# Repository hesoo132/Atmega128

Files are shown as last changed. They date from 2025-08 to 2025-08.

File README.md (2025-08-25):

# ATmega128A Security System Board

> Keypad + LCD + Bluetooth(HC‑06) + Shock Sensor(SW‑420) + Servo Lock + Buzzer
> Education & Smart Access Control Prototyping Platform

---

## 🔎 Overview
The **ATmega128A Security System Board** is a compact AVR platform for **learning, prototyping, and access‑control demos**.
It integrates **12 V → 5 V/3.3 V** power, **USB‑UART**, **ISP programming**, **keypad+LCD UI**, **HC‑06 Bluetooth**, **SW‑420 vibration detection**, **servo lock**, and **buzzer alerts**.

---

## 📸 PCB Overview
| Top View | Bottom View |
|---|---|
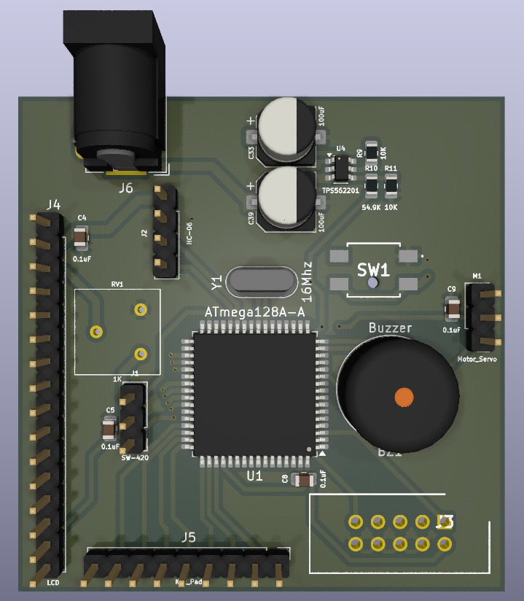
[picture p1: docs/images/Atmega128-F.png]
Top
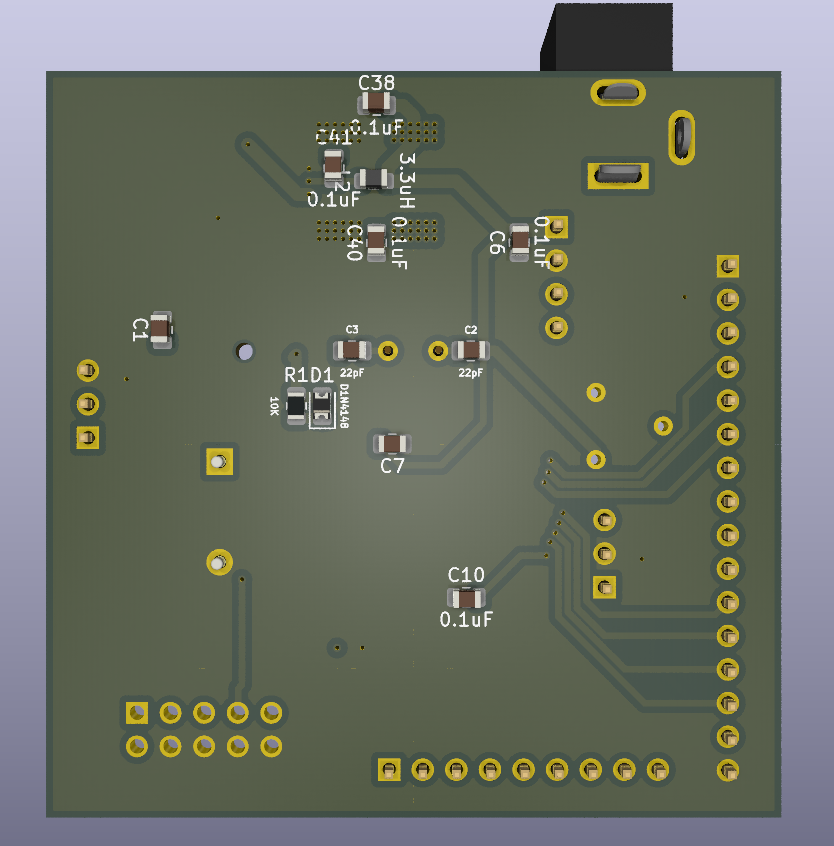
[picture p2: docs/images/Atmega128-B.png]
Bottom
|  |  |

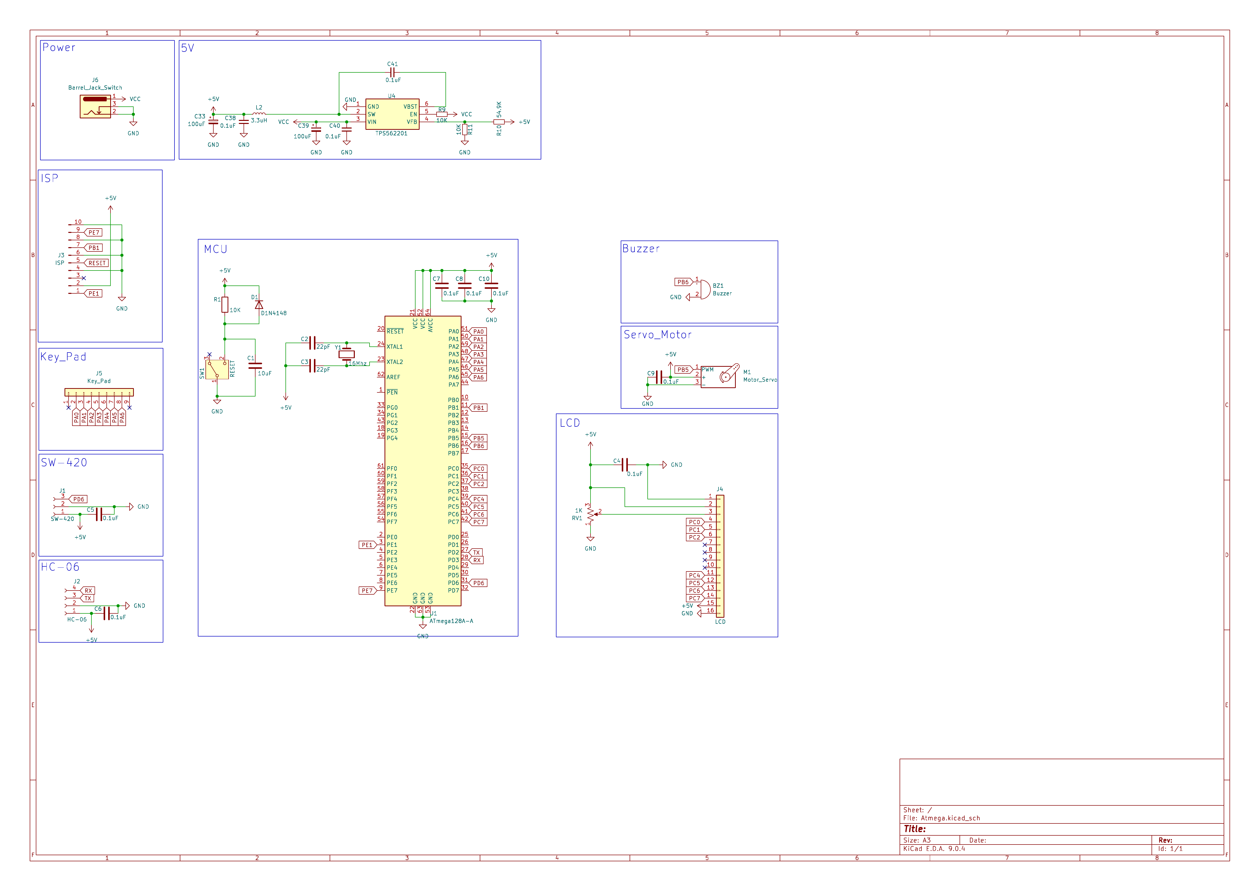
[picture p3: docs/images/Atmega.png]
Schematic
> Schematics (PNG): 

---

## 📑 Design Resources
- **MCU**: ATmega128A‑AU (8‑bit AVR)
- **EDA**: KiCad 9.0.x
- **Board**: 2‑layer

---

## ⚙️ Key Hardware Notes
- **Power**: 12 V barrel jack → **TPS562201‑5.0 / TPS562201‑3.3** rails
- **Clock**: 16 MHz crystal
- **Programming**: **ISP header** (AVRDUDE/USBasp/Atmel‑ICE)
- **USB‑UART**: FT232RL (debug console / host comms)
- **UI/Peripherals**:
  - **Keypad (J5)**: enter/change password
  - **LCD (J4)**: show result/tries/lockout timer
  - **Servo**: unlock on success; stay locked on failure
  - **Buzzer**: success/fail tone + vibration alarm
  - **SW‑420 (J1)**: shock/vibration tamper detection
  - **HC‑06 (J2)**: Bluetooth data exchange

---

## 🔐 Security‑Oriented Features
| Module | Role |
|---|---|
| **Keypad (J5)** | Password entry / change |
| **LCD (J4)** | Status, error, lockout seconds |
| **Servo** | Door actuation (open on correct PIN) |
| **Buzzer** | Wrong PIN & vibration alarm |
| **SW‑420** | Tamper/shock detection |
| **HC‑06** | Remote monitor & control (UART over BT) |

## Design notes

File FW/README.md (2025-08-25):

# 🔐 ATmega128A Firmware – Smart Locker System

## 🔎 Overview
This firmware is designed for the **ATmega128A Security System Board**.
It integrates keypad password entry, LCD feedback, Bluetooth control, servo motor door actuation, vibration detection, and buzzer alarms.
The system supports **PIN verification, password change, vibration-based tamper alerts, lockout after repeated failures, and remote Bluetooth door control**.

---

## 📊 System Block Diagram
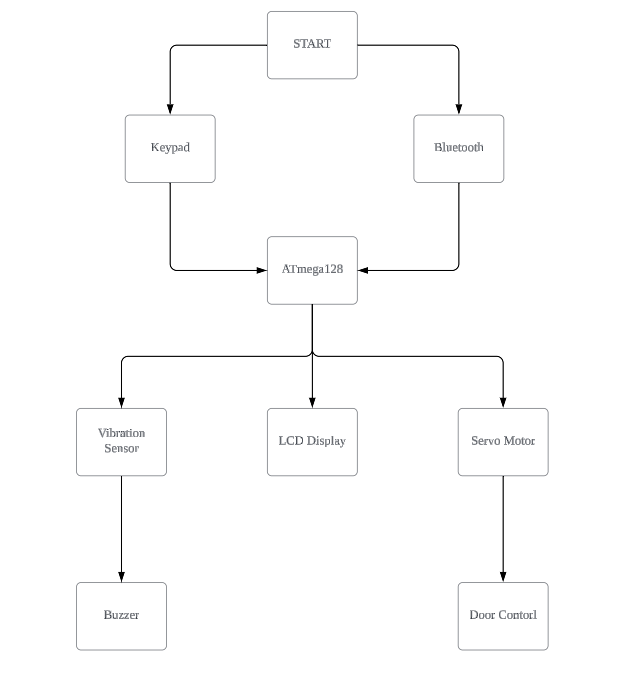
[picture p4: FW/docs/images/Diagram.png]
System Diagram


---

## ⚙️ Features

- **Password Authentication**
  - 4-digit PIN entry via **Keypad (J5)**
  - Password change supported (`*` → old password → new password)
  - LCD shows password entry & system status

- **Door Control**
  - **Servo motor** opens on correct password or Bluetooth `1` command
  - Auto-closes after 10 seconds or `#` press
  - Bluetooth `0` command forces door close

- **Tamper Detection**
  - **SW-420 vibration sensor** monitors physical shock
  - >5 consecutive hits triggers buzzer alarm + LCD warning
  - Resets to password input screen afterward

- **Buzzer Alerts**
  - Success melody (correct PIN / open door)
  - Warning tone (wrong PIN / vibration detected)

- **Security Lockout**
  - After **5 failed attempts**, system locks for **30 seconds**
  - LCD shows countdown timer

- **Bluetooth Remote Control**
  - `1` = Open door
  - `0` = Close door

---

## 🧩 Key Functions in Code

- `InitDevices()` → Peripheral initialization (PWM, UART, GPIO)
- `SetServoAngle(angle)` → Servo motor positioning (−90° closed, +90° open)
- `PlayTone(f, d)` → Generate tone on buzzer (frequency, duration)
- `PlaySuccessTune()` → Melody on successful unlock
- `CheckVibrationSensor()` → Detect repeated vibration & raise alarm
- `KeyScan()` → 4x3 keypad scanning with debounce + beep feedback
- `BluetoothReceive()` → UART0 data polling (HC-06)
- `DisplayMessage(line1, line2)` → LCD line output utility

---

## 📜 Example Workflow
1. **Startup**
   - LCD: `Welcome! Daejin Locker`
   - Prompt: `Insert Password`

2. **Password Handling**
   - User enters 4-digit PIN + `#`
   - If correct → door opens, melody plays
   - If wrong → error tone, retry prompt

3. **Failure Handling**
   - After 5 wrong attempts → 30s lockout
   - LCD shows countdown: `Wait: XX sec`

4. **Tamper Handling**
   - Vibration detected ≥5 times → alarm tone
   - LCD: `Don't hit it!!` → resets to password prompt

5. **Bluetooth**
   - Receive `1` → Door opens
   - Receive `0` → Door closes

---

## 📱 Mobile App (MIT App Inventor)

A companion **Android App** was created using **MIT App Inventor**  
to control the ATmega128A Smart Locker via Bluetooth.

| Main Screen | Sign Up Screen | Control Screen |
|---|---|---|
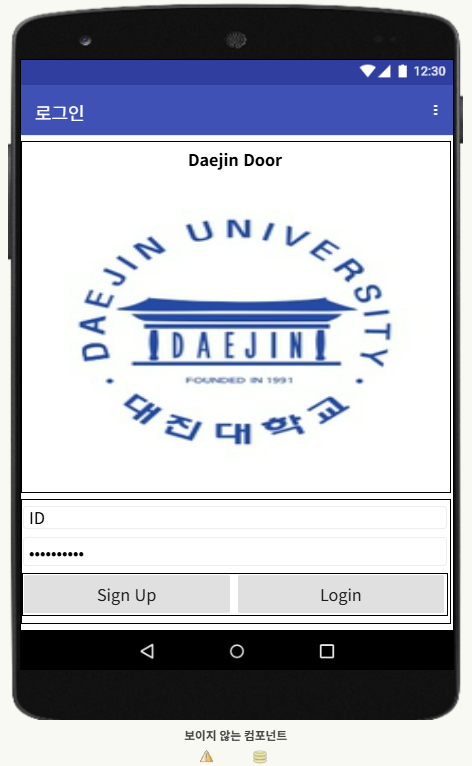
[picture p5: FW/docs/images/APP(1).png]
Main
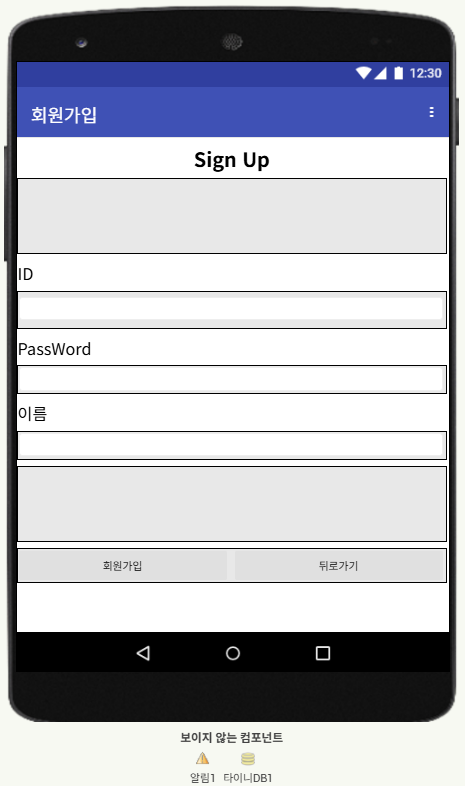
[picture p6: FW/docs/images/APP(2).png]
Sign Up
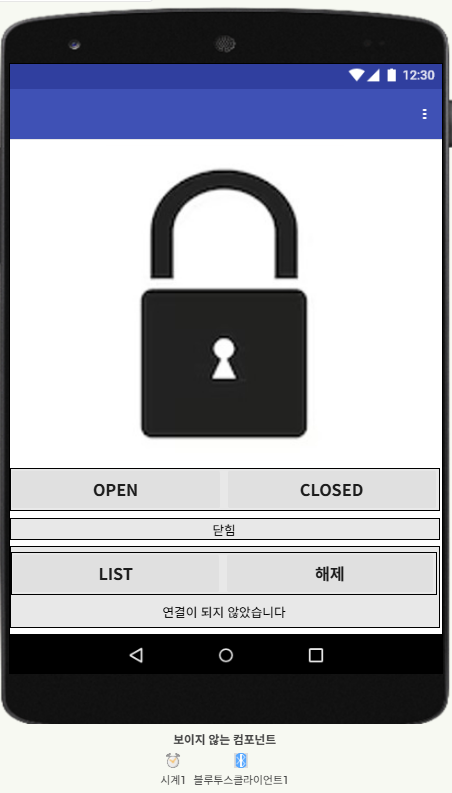
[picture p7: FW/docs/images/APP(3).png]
Control
|  |  |  |

- **Main Screen**
  - Bluetooth pairing, Open/Close control
  - Door status feedback  

- **Login Screen**
  - User authentication (ID + Password)

- **Sign Up Screen**
  - Register new users (ID, Password, Name)

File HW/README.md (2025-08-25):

# ATmega128A Development Board

## 🔎 Overview
The **ATmega128A Development Board** is a versatile embedded platform for **AVR microcontroller learning, prototyping, and embedded system design**.  
It integrates stable power delivery, multiple communication interfaces, keypad & LCD modules, and expansion connectors for external devices.

---

## 📸 PCB Overview
| Top View | Bottom View |
|---|---|
| Top | Bottom |

---

## 📑 Design Resources
- **Schematics**: [Atmega.pdf](Atmega.pdf) (KiCad 9.0.4)

---

## 🔧 Key Hardware Notes
- **EDA Tool**: KiCad 9.0.4  
- **PCB Stackup**: 2-layer standard  
- **MCU**: ATmega128A-AU (8-bit AVR, Ports A–G exposed)  
- **Power**: 12 V input → 5 V & 3.3 V rails (TPS562201 regulators)  
- **Interfaces**: USB-to-Serial (FT232RL), ISP programmer header  
- **User IO**: Keypad, LCD, Servo motor, Buzzer, LEDs  
- **Sensors**: SW-420 vibration/shock sensor  
- **Communication**: HC-06 Bluetooth module

---

## 🧩 Schematic Highlights
MCU
### 1) MCU — ATmega128A-AU  
- **Role**: Central controller for all peripherals  
- **Features**: GPIO Ports A–G, external 16 MHz crystal, reset circuit  
- **Purpose**: Main processing unit for password and control logic

---

### 2) Power
- **Input**: Barrel Jack (12 V)  
- **Regulators**: TPS562201-5.0 & TPS562201-3.3  
- **Purpose**: Stable dual-voltage supply for mixed 5 V / 3.3 V peripherals

---

### 3) Communication 
- **USB-to-Serial**: FT232RL for PC connection & firmware upload  
- **ISP**: 6-pin header for direct programming  
- **Bluetooth (J2)**: HC-06 for wireless communication

---

### 4) User I/O
- **Keypad (J5)**: Password input & modification  
- **LCD (J4)**: Password confirmation, error display, lockout countdown  
- **LEDs (D1–D4)**: Status indicators  
- **Buzzer**: Alarm on wrong password or vibration detection  
- **Servo Motor**: Unlocks on correct password; locked otherwise  
- **SW-420 Sensor (J1)**: Detects vibration/shock for tamper alert

---

## ✅ Progress
- [x] Schematics completed  
- [x] PCB fabricated  
- [x] Power supply tested (5 V / 3.3 V OK)  
- [x] USB-Serial & ISP programming validated  
- [x] Keypad & LCD integrated  
- [x] Bluetooth bring-up (HC-06)  
- [x] Security application firmware in progress

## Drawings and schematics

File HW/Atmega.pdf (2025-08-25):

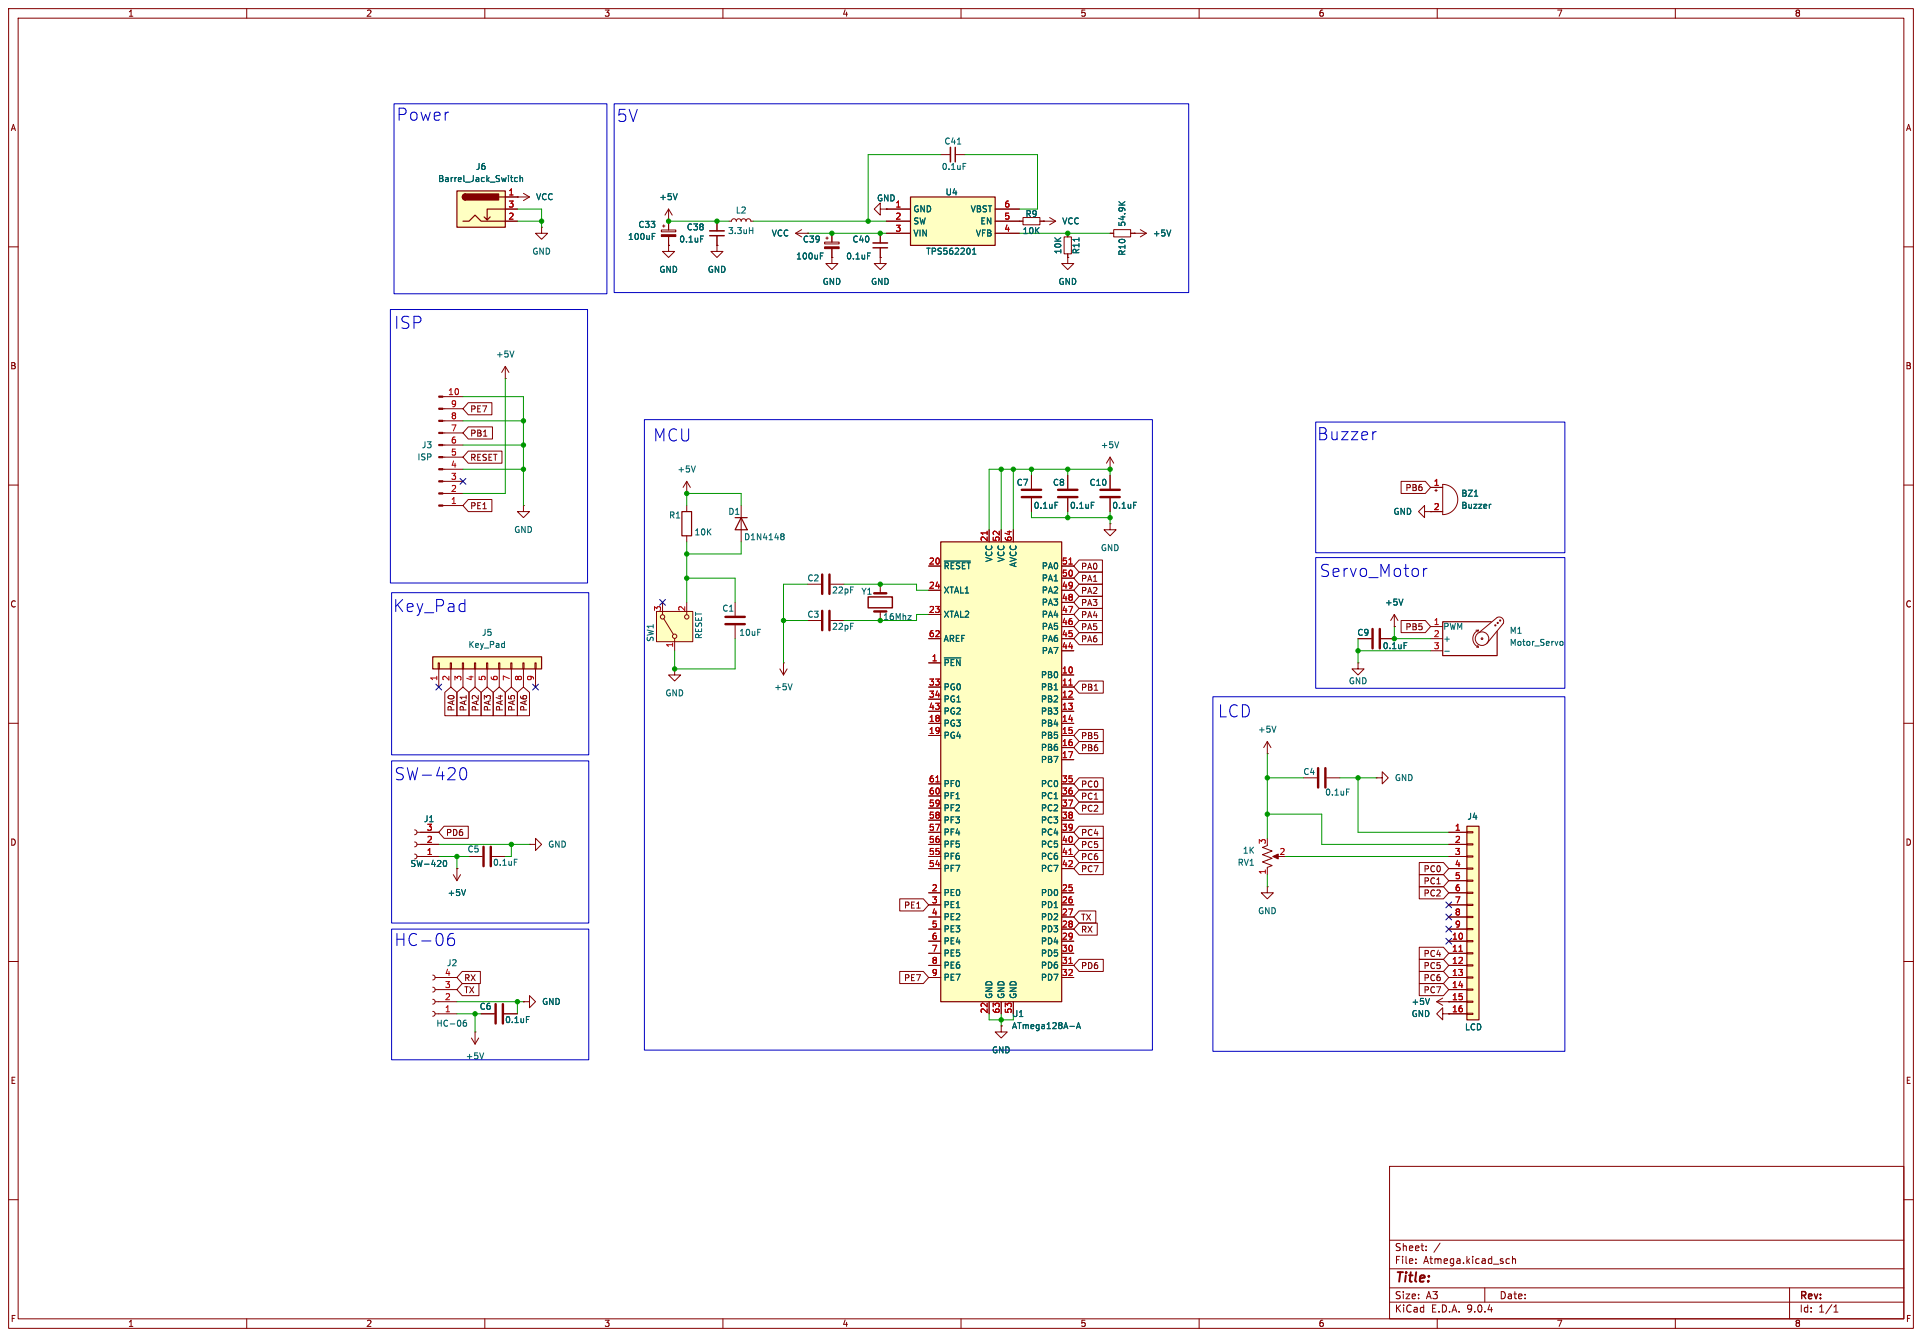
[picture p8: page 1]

Id: 1/1 Title: File: Atmega.kicad_sch Sheet: /

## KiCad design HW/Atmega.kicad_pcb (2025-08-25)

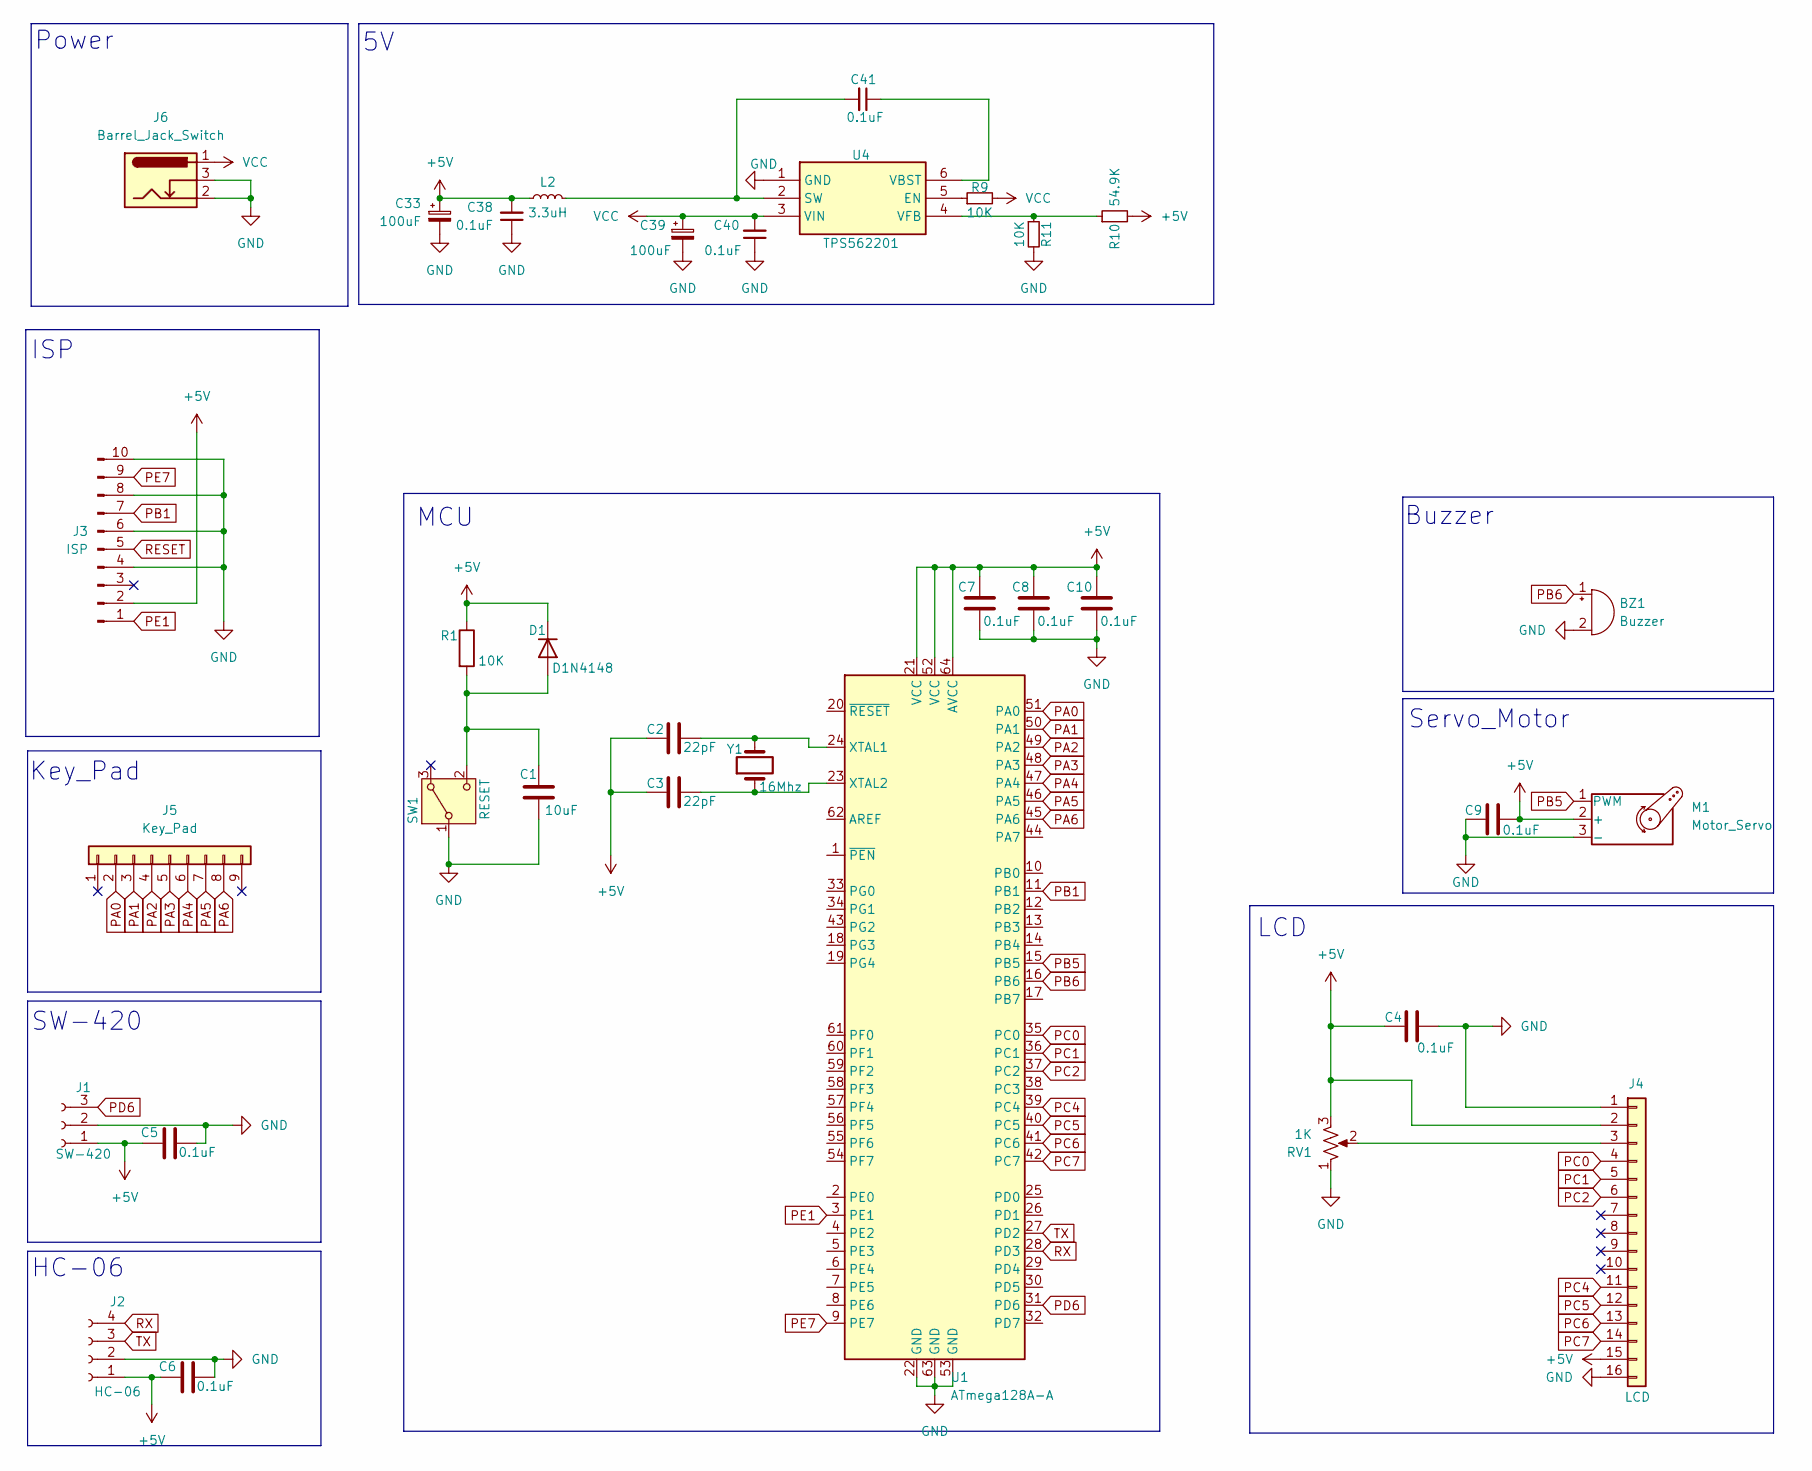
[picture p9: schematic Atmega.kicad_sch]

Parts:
BZ1: Buzzer; Buzzer_12x9.5RM7.6
C1: 10uF; C_0805_2012Metric
C2, C3: 22pF; C_0805_2012Metric
C4, C5, C6, C7, C8, C9, C10, C38, C40, C41: 0.1uF; C_0805_2012Metric
C33, C39: 100uF; CP_Elec_6.3x5.9
D1: D1N4148; D_0805_2012Metric
J1: SW-420; PinHeader_1x03_P2.54mm_Vertical
J2: HC-06; PinHeader_1x04_P2.54mm_Vertical
J3: ISP; SHDR10W64P254_2X5_2036X885X925P
J4: LCD; PinHeader_1x16_P2.54mm_Vertical
J5: Key_Pad; PinHeader_1x09_P2.54mm_Vertical
J6: Barrel_Jack_Switch; BarrelJack_GCT_DCJ200-10-A_Horizontal
L2: 3.3uH; L_0805_2012Metric
M1: Motor_Servo; PinHeader_1x03_P2.54mm_Vertical
R1, R9, R11: 10K; R_0805_2012Metric
R10: 54.9K; R_0805_2012Metric
RV1: 1K; Potentiometer_Bourns_3386F_Vertical
SW1: RESET; TLSMDT3C020GLFS
U1: ATmega128A-A; TQFP-64_14x14mm_P0.8mm
U4: TPS562201; SOT-23-6; Mouser Part Number 595-TPS562201DDCR
Y1: 16Mhz; Crystal_HC52-6mm_Vertical

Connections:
+5V: C2.1, C3.1, C4.1, C5.1, C6.1, C7.2, C8.2, C9.1, C10.2, C33.1, C38.2, D1.1 (K), J1.1, J2.1, J3.2, J4.2, J4.15, L2.2, M1.2 (+), R1.1, R10.2, RV1.3, U1.21 (VCC), U1.52 (VCC), U1.64 (AVCC)
GND: BZ1.2 (-), C1.2, C4.2, C5.2, C6.2, C7.1, C8.1, C9.2, C10.1, C33.2, C38.1, C39.2, C40.1, J1.2, J2.2, J3.4, J3.6, J3.8, J3.10, J4.1, J4.16, J6.2, J6.3, M1.3 (-), R11.2, RV1.1, SW1.1 (B), U1.22 (GND), U1.53 (GND), U1.63 (GND), U4.1 (GND)
unnamed: C1.1, D1.2 (A), R1.2, SW1.2 (C)
unnamed: J4.3, RV1.2
unnamed: C2.2, U1.24 (XTAL1), Y1.2
unnamed: C3.2, U1.23 (XTAL2), Y1.1
unnamed: R9.1, U4.5 (EN)
unnamed: C41.2, L2.1, U4.2 (SW)
unnamed: C41.1, U4.6 (VBST)
unnamed: R10.1, R11.1, U4.4 (VFB)
PA0: J5.2, U1.51 (PA0)
PA1: J5.3, U1.50 (PA1)
PA2: J5.4, U1.49 (PA2)
PA3: J5.5, U1.48 (PA3)
PA4: J5.6, U1.47 (PA4)
PA5: J5.7, U1.46 (PA5)
PA6: J5.8, U1.45 (PA6)
PB1: J3.7, U1.11 (PB1)
PB5: M1.1 (PWM), U1.15 (PB5)
PB6: BZ1.1 (+), U1.16 (PB6)
PC0: J4.4, U1.35 (PC0)
PC1: J4.5, U1.36 (PC1)
PC2: J4.6, U1.37 (PC2)
PC4: J4.11, U1.39 (PC4)
PC5: J4.12, U1.40 (PC5)
PC6: J4.13, U1.41 (PC6)
PC7: J4.14, U1.42 (PC7)
PD6: J1.3, U1.31 (PD6)
PE1: J3.1, U1.3 (PE1)
PE7: J3.9, U1.9 (PE7)
RESET: J3.5
RX: J2.4, U1.28 (PD3)
TX: J2.3, U1.27 (PD2)
VCC: C39.1, C40.2, J6.1, R9.2, U4.3 (VIN)

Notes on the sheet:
Buzzer
ISP
HC-06
Servo_Motor
LCD
Power
MCU
SW-420
Key_Pad

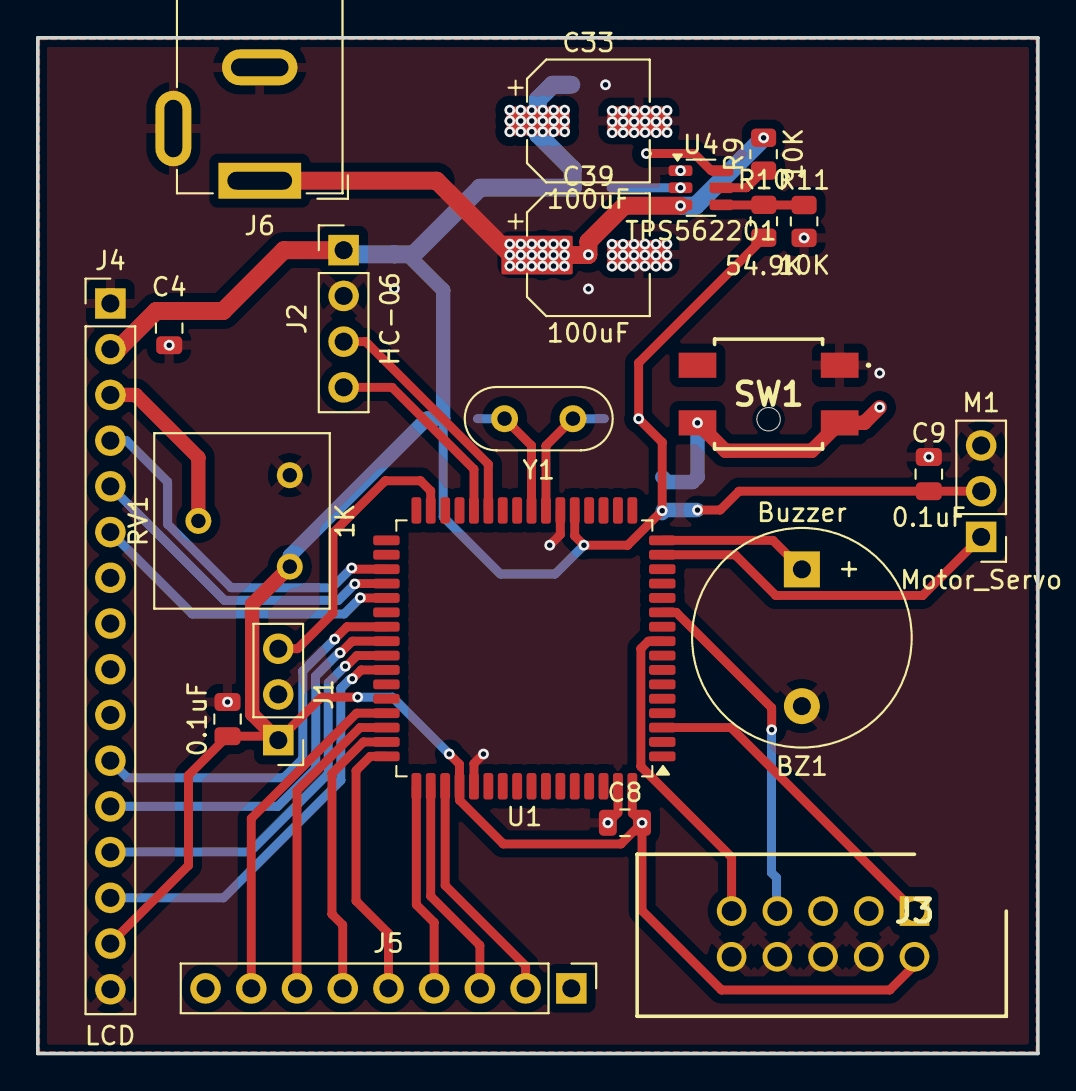
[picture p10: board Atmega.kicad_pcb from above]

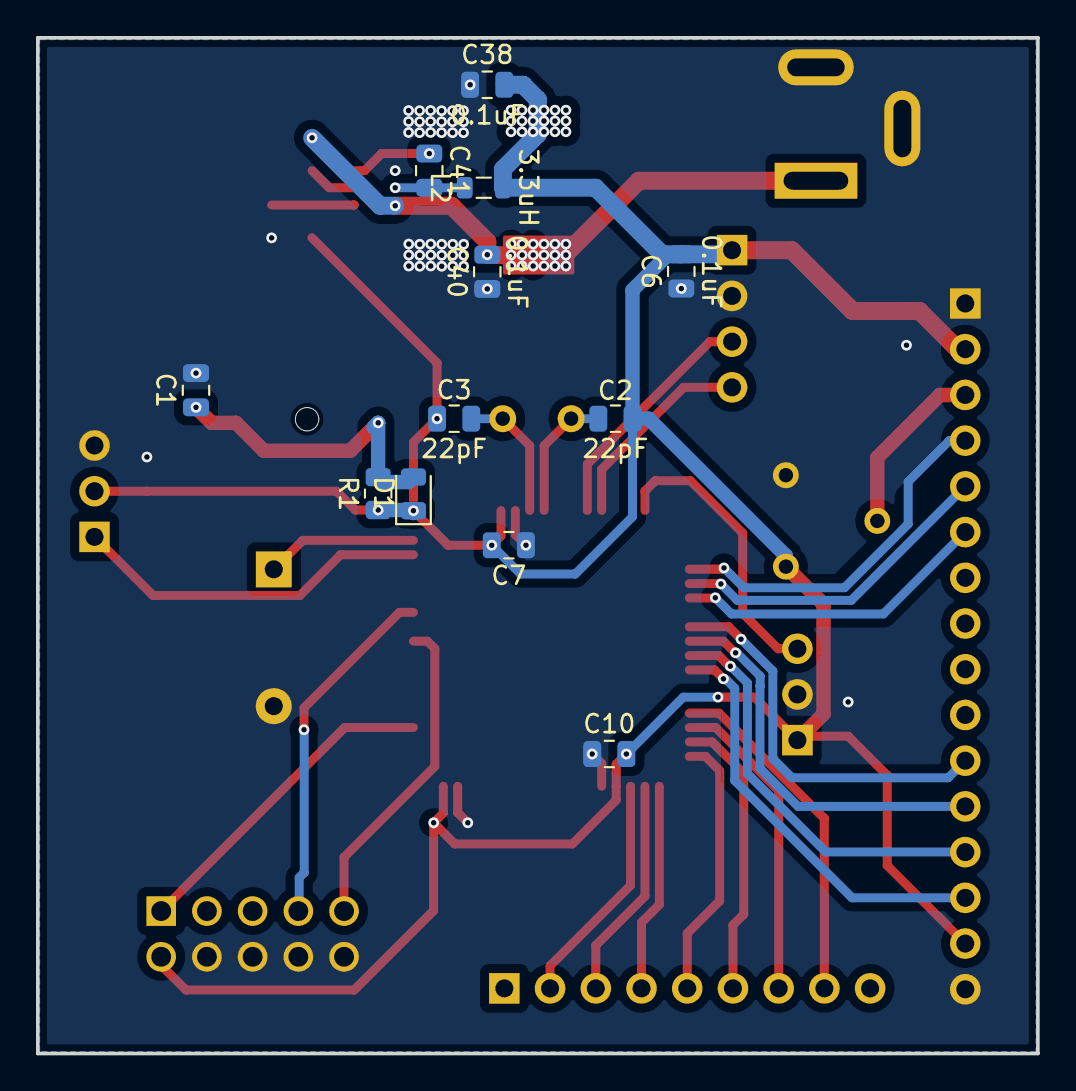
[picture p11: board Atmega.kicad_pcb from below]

Board: 2 copper layers, 55.6 x 56.4 mm, 34 parts (12 on the bottom side), 33 nets.
